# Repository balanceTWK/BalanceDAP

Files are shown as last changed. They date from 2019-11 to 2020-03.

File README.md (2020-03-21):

# BalanceDAP

本项目长期偶尔更新！如有疑问，请[邮箱](mailto:balancetwk@yeah.net)联系我。balanceTWK@yeah.net

代码工程：基于开源免费的 [DAPLink](https://github.com/ARMmbed/DAPLink), [RT-Thread](https://github.com/RT-Thread/rt-thread),

电路板工程：使用开源免费的 [KiCad](http://docs.kicad-pcb.org/) 构建。

本仓库同样开源免费，遵守 [Apache License 2.0 协议](./LICENSE).

## 电路板效果图

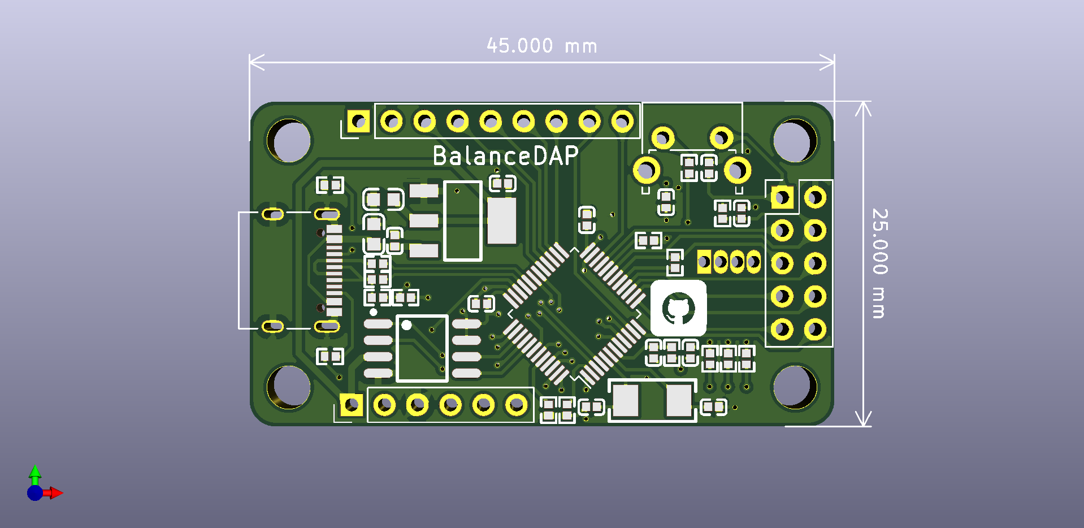
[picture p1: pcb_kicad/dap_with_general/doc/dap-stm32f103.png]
pcb图


## 移植成 rt-thread 后的效果：

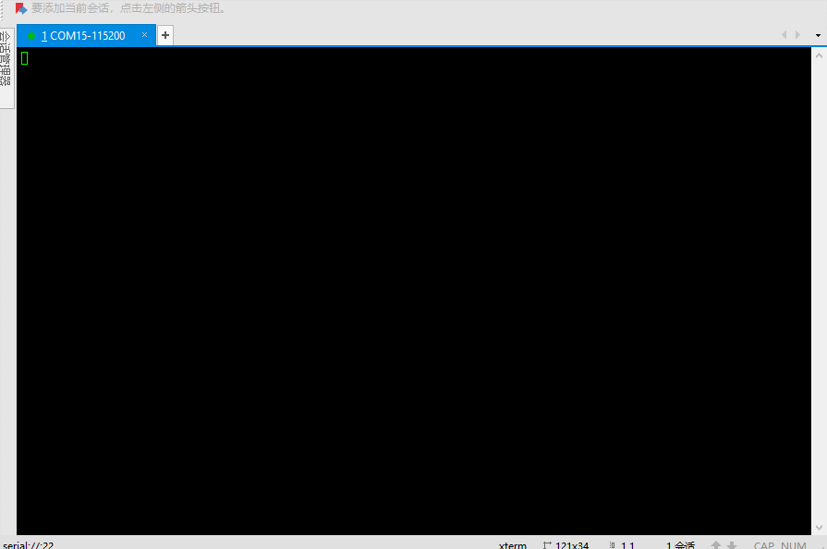
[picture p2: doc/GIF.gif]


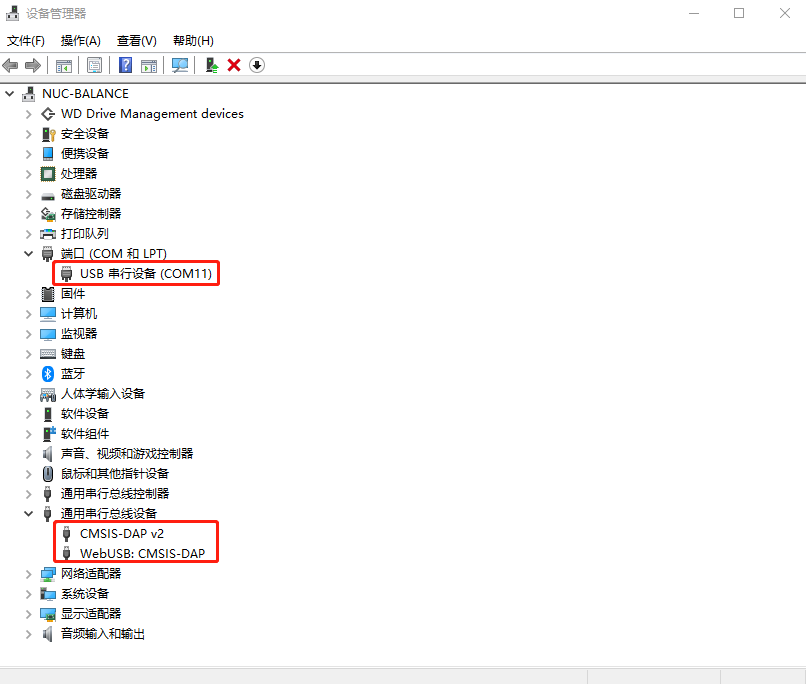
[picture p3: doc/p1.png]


## 问题汇总：

 1. 关于使用 KiCad 打开工程出现原理图缺失元器件的问题：原因是没有安装和作者相同的 KiCad 库，请到此 [链接](https://github.com/balanceTWK/lc_kicad_lib)  处下载。

 2. 关于 MDK 不识别 CMSIS-DAP V2 的问题：参考 /doc 目录下 [Notes.md](doc/Notes.md)。

 ## 感谢：

[@Guozhanxin](https://github.com/Guozhanxin)

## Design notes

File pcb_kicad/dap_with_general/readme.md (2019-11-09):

# DAPLink 全功能版本

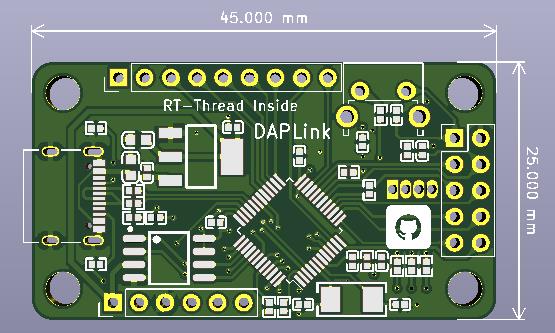
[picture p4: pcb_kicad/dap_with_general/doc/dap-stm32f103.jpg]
pcb图


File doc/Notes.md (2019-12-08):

# µVISION DEBUGGER: µVISION does not detect Mbed DAPLink
Information in this knowledgebase article applies to:

  - MDK version 5.28 and earlier
  - DAPLink versions which are based on CMSIS-DAP V2

## SYMPTOM
µVision version 5.28 or before does not detect an Mbed DAPLink debug adapter which is based on CMSIS-DAP V2.

## CAUSE
An Mbed DAPLink device is a USB composite device which consists of several USB classes (MSC, CDC, HID, WinUSB). Since CMSIS-DAP V2, a WinUSB bulk transfer is used instead of USB-HID. The µVision CMSIS-DAP debug driver always used the first interface (0) of a USB composite device to communicate. However, new DAPLink releases have the MSC on interface 0 and WinUSB on a higher interface number.

## RESOLUTION
Download the attached ZIP file and extract the CMSIS-DAP debug driver file (CMSIS_DAP.dll V0.2.14.1) into the MDK installation folder \ARM\BIN. If the default installation path was used, this is the folder C:\Keil_v5\ARM\BIN

This patch fixes the issues described as 'current limitation #1' for this GitHub commit.

## STATUS
This will be fixed in MDK version 5.29 and later.

## MORE INFORMATION
  - [Mbed DAPLink GitHub repository](https://github.com/ARMmbed/DAPLink)
  - [Arm CMSIS-DAP repository](https://arm-software.github.io/CMSIS_5/DAP/html/index.html)

## ATTACHED FILES
Request the [files attached](./4170.zip) to this knowledgebase article.

Last Reviewed: Wednesday, September 25, 2019

Original [link](http://www.keil.com/support/docs/4170.htm)

---------------------------------------------------------

# µVISION 调试器：µVISION 无法检测到 Mbed DAPLink

本知识库文章中的信息适用于：
  - MDK 版本 5.28 和更早版本
  - 基于 CMSIS-DAP V2 的 DAPLink 版本

## 症状
µVision 版本 5.28 或更低版本无法检测到基于 CMSIS-DAP V2 的 Mbed DAPLink 调试适配器。

## 原因
Mbed DAPLink 设备是一种 USB 复合设备，它由几个 USB 类（MSC，CDC，HID，WinUSB）组成。从 CMSIS-DAP V2 开始，将使用 WinUSB 批量传输代替 USB-HID。µVision CMSIS-DAP 调试驱动程序始终使用 USB 复合设备的第一个接口（0）进行通信。但是，新的 DAPLink 版本在接口 0 上具有 MSC，而在更高接口号上具有 WinUSB。

## 解决方法
下载随附的 ZIP 文件，并将 CMSIS-DAP 调试驱动程序文件（CMSIS_DAP.dll V0.2.14.1）解压缩到 MDK 安装文件夹 \ARM\BIN 中。如果使用默认安装路径，则该文件夹为 C:\Keil_v5\ARM\BIN

该补丁修复了此 GitHub commit 称为'当前限制＃1'的问题。

## 状态
这将在 MDK 5.29 版和更高版本中修复。

## 更多信息
  - [Mbed DAPLink GitHub 存储库](https://github.com/ARMmbed/DAPLink)
  - [Arm CMSIS-DAP 存储库](https://arm-software.github.io/CMSIS_5/DAP/html/index.html)

## 附件
请求附加到此知识库文章的 [文件](./4170.zip)。

上次审查：2019 年 9 月 25 日星期三

原文[链接](http://www.keil.com/support/docs/4170.htm)

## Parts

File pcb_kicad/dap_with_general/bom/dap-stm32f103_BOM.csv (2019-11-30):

Comment | Description | Designator | Footprint | LibRef | Pins | Quantity | PartNumber | url
0402_100nF__104_10%_16V | desc | C11,C4,C12,C13,C3,C14,C15,C5,C8, | 0402_C | libref | 2 | 9
0402_22pF__220_5%_50V | desc | C2,C1, | 0402_C | libref | 2 | 2
0603_10uF__106_10%_10V | desc | C6,C10, | 0603_C | libref | 2 | 2
LOGO | desc | G***, | github | libref | 0 | 1
0402_510Ω__5100_1% | desc | R10,R11,R12,R9, | 0402_R | libref | 2 | 4
0402_1.5KΩ__1501_1% | desc | R13, | 0402_R | libref | 2 | 1
0402_22Ω__22R0_1% | desc | R14,R15, | 0402_R | libref | 2 | 2
0402_0Ω__0R0_1% | desc | R16, | 0402_R | libref | 2 | 1
0402_100KΩ__1003_1% | desc | R3, | 0402_R | libref | 2 | 1
0402_10KΩ__1002_1% | desc | R5,R4,R2,R1, | 0402_R | libref | 2 | 4
0402_100Ω__1000_1% | desc | R6, | 0402_R | libref | 2 | 1
0402_5.1KΩ__5101_1% | desc | R8,R7, | 0402_R | libref | 2 | 2
W25Q128FVSIG_[C35101] | desc | U1, | SOIC-8_208MIL | libref | 8 | 1
STM32F103CBTx | desc | U2, | LQFP-48_7x7mm_P0.5mm | libref | 48 | 1
SOT-223_AMS1117-3.3 | desc | VR1, | SOT-223 | libref | 4 | 1
SMD-5032_2P_8MHz_20ppm_20pF | desc | Y1, | SMD-5032_2P | libref | 2 | 1
Through Hole Items
USB_C_Receptacle_USB2.0 | desc | J1, | USB_C_Receptacle_Palconn_UTC16-G | libref | 22 | 1
Conn_02x05_Top_Bottom | desc | J2, | PinHeader_2x05_P2.54mm_Vertical | libref | 10 | 1
Conn_01x09 | desc | J3, | PinHeader_1x09_P2.54mm_Vertical | libref | 9 | 1
Conn_01x06 | desc | J4, | PinHeader_1x06_P2.54mm_Vertical | libref | 6 | 1
SW_Push | desc | SW1, | SW_Tactile_SPST_Angled_PTS645Vx58-2LFS | libref | 4 | 1
LED_RCBG | desc | D1, | LED_D5.0mm-4_RGB | libref | 4 | 1

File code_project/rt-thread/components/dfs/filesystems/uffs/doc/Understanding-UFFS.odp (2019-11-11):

## Understanding UFFS

Ricky Zheng

< ricky_gz_zheng@yahoo.co.nz >

Created: March 2007

Last modified: Nov 2011

## Content

- Why UFFS ?
- Design goal
- Flash: NOR vs NAND ?
- What's wrong with FAT ?
- UFFS basic idea
  - Serial number
  - Tree in memory
  - Journalizing
- UFFS architecture
  - UFFS device
  - Mount point
  - UFFS nodes tree
  - Mounting UFFS
  - Page spare/UFFS tags
  - Block info cache
  - UFFS page buffer
  - Block recover
  - Bad block management
  - How ECC works ?
  - Flash interface
- What's next ?
  - UFFS2

## Why UFFS ?

- JFFS/JFFS2
  - Can't go out of Linux/MTD
  - Memory monster
- YAFFS/YAFFS2 still consumes too much RAM
  - 64M FLASH, 500 files ==> 410K RAM
- No open source lightweight flash file system exists yet ...

## UFFS design goal

- Ultra low cost
  - Low memory cost
  - Fast booting
- Superb Stability
  - Constant RAM consumption, support static memory allocation
  - Guaranteed integrity across unexpected power losses
  - Bad block tolerant, ECC and ware leveling
- NAND flash friendly
  - Support small (512B) or large page (up to 4KB) size
  - Support SLC and MLC
  - Support software ECC or hardware ECC / RS-ECC
  - Direct flash interface
- Well Emulated on PC platform, easy for debugging

## Flash: NOR vs NAND

- NOR:
  - Random access for read
  - Big block (minimal erase unit)
  - Byte programing
  - Slow erasing/programing
- NAND:
  - Page/spare access for read
  - Small block
  - Page/spare programing (with limited splits/Restricted rewrite)
  - Fast erasing/programing
  - Delivered with bad blocks

## NAND Flash Basic

Page data

Spare

Block

Erase: '0'->'1', Write/Program: '1'->'0'

## What's wrong with FAT

- Need FTL (which may cost many RAM)
- Big FAT table,slow down the whole system
- Vulnerable when unexpectedly interrupted while updating FAT or File info

FAT

File info

Changes

Write File

Changes

File data

Changes

## UFFS basic idea(1)

Parent

Serial

Parent

Serial

Parent

Serial

Parent

Serial

Parent

Serial

Parent

Serial

Parent

Serial

Parent

Serial

Parent

Serial

- Use unique parent/serial number pair to:
  - Identify blocks
  - Build relationships

ROOT

Parent: 16 bit

Serial: 16 bit

## UFFS basic idea(2)

- Build the relationship tree in memory when mounting UFFS:
  - Erased blocks
  - Bad blocks
  - Hash tables (serial number as key)
    - Dir table
    - File table
    - File data table
- Tree node size: 16 bytes
  - Memory cost: 16 * total_blocks

## UFFS basic idea(3)

- Journalizing
  - Write to a new block/page instead of modify the old one.
  - Use circular time stamp: 00->01->11->00>...
  - Check and correct conflicts while mounting UFFS
  - Using “mini-header” eliminates partial page programing requirement

## UFFS Device

- UFFS Device & Mount Point

extern uffs_Device uffs_rootDev;

extern uffs_Device uffs_dataDev;

static struct uffs_mountTableSt femu_MountTbl[] = {

{&uffs_rootDev, 0, 200, "/"},

{&uffs_dataDev, 201, -1, "/data/"},

{NULL, 0, 0, NULL},

};

“/”

“/data/”

UFFS Device ===> Partition
UFFS Device: individual flash ops, cache/buffer, tree nodes ...

## UFFS node tree

- UFFS nodes tree

UFFS device

Bad blocks

Erased blocks

Dir nodes

File nodes

Data nodes

Hash table, serial as the key

block,next

block,next

block,parent,serial,sum,next

block,parent,serial,sum,length(4),next

block,parent,serial,length(2),next

sizeof(TreeNode) = 16B

## UFFS Mounting

- Mounting UFFS

Step 1:

  - Scan page spares*, classify DIR/FILE/DATA nodes
  - Check bad block
  - Check interrupted writing

Step 2:

  - Randomize erased blocks

Step3:

  - Check DATA nodes,take care orphan nodes

Super fast !

* UFFS only read a few spares (normally one or two) from each block rather then all spares !!

UFFS device

Bad blocks

Erased blocks

Dir nodes

File nodes

Data nodes

## UFFS tags

- Page spare/UFFS tags

struct uffs_TagStoreSt {

u32 dirty:1;

u32 valid:1;

u32 type:2;

u32 block_ts:2;

u32 data_len:12;

u32 serial:14;

u32 parent:10;

u32 page_id:6;

u32 reserved:4;

u32 tag_ecc:12;

};

sizeof(struct uffs_TagStoreSt) = 8, small enough to store on spare area

* Note: if using RS-ECC on small page MLC, then tag may store on page data area

## UFFS block info cache

- UFFS block info cache

struct uffs_pageSpareSt {

u8 expired:1;

uffs_Tags tag;

};

struct uffs_blockInfoSt {

struct uffs_blockInfoSt *next;

struct uffs_blockInfoSt *prev;

u16 blockNum;

struct uffs_pageSpareSt *spares;

int expiredCount;

int refCount;

};

uffs_config.h:

MAX_CACHED_BLOCK_INFO(5 ~10)

Memory: 40 bytes for each cached info

## UFFS page buffer

- UFFS page buffer

struct uffs_BufSt{

struct uffs_BufSt *next;

struct uffs_BufSt *prev;

struct uffs_BufSt *nextDirty;

struct uffs_BufSt *prevDirty;

u8 type;

u8 ext_mark;

u16 parent;

u16 serial;

u16 pageID;

u16 mark;

u16 refCount;

u16 dataLen;

u8 * data;

u8 * header;

};

uffs_config.h:

MAX_PAGE_BUFFERS (10 ~ 40)

Memory: (40 + page_size) each buffer

## UFFS page status

Valid page

Discarded page

Free page

- Free page: no page id assigned yet. Free pages are always on the bottom.
- Valid page: the page with a id and have max page offset
- Discarded page: the page with page id, there are one or more pages have the same id and bigger page offset.
- Unknown status: interrupted while writing a page.

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
## UFFS block status

Valid page

Discarded page

Free page

- Bad block
- Free/Erased block
- Non-full loaded block (have one or more free pages)
- Full loaded block (no free page, page id = physical page offset)

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
Bad block

Free block

Non-full loaded block

13

14

15

Full loaded block

## UFFS block recover(1)

- Block recover happens when:
  - No more free pages available inside the block and
  - Data were modified and/or
  - Flush the buffer
- Block recover steps:
  - (1)Get a free/erased block from erased block list
  - (2)Copy pages from old block, write to new block with newer timestamps
  - (3)Erase the old block
  - (4)Put the old block to erased block list
  - Note: (1) and (4) are operating in memory. (2) and (3) identified by timestamps, all steps allow to be interrupted at any time ! (Guaranteed integrity across unexpected power losses)

## UFFS block recover(2)

- No block recover if there are enough free pages

Block 1234

0

Block 1234

0

1

1

Since there are free pages, no block recover happens.

Mark old page as discarded, and generate a new page.

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
Valid page

Discarded page

Free page

## UFFS block recover(3)

- Recover a non-full loaded block

Block 1234

0

Block 5678

0

1

No more free page available in this block, modify any pages from 0-7, or add a new page 8, will cause block recovering.

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
Valid page

Discarded page

Free page

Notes: See uffs_buf.c: static URET _BufFlush_Exist_With_BlockCover ( uffs_Device *dev, TreeNode *node, uffs_blockInfo *bc )

## UFFS block recover(4)

- Recover a full-loaded block

Block 1234

0

Block 5678

0

Modify any page of full-loaded block will cause block recovering.

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
Valid page

Discarded page

Free page

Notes: See uffs_buf.c: static URET _BufFlush_Exist_With_BlockCover ( uffs_Device *dev, TreeNode *node, uffs_blockInfo *bc )

## UFFS Page layout

Status byte

mini-

header

Seal byte

ECC

DATA

Tag

- Mini-header (4B) and DATA on page data area, Tag, ECC and 'seal byte' on spare area
- In some case (for example, when using hardware RS-ECC on small page MLC), you can treat the whole NAND page as one body, blur the page data and spare area boundary.
- The 'status byte': this is the first byte of mini-header. If status byte is not 0xFF – this page is “dirty”, page program already started.
- The 'seal byte': this is the last byte of spare data. If seal byte is not 0xFF – this page is “sealed”, all data and tag/ECC have been programmed successfully.

## UFFS bad block management

- Bad block discover when mounting UFFS
- Bad block discover when read/write/erase
  - Try ECC error correct
  - If ECC fail, there is no way get valid data
  - Do not process bad block immediately, leave it at the end of Read/Write operation.
  - Only handle one bad block during the one read/write operation.
- Check bad block when formating UFFS

## How ECC works ? (1)

- XOR: A ^ B = C
  - 0 ^ 0 = 0
  - 1 ^ 0 = 1
  - 0 ^ 1 = 1
  - 1 ^ 1 = 0
- Knowing any two of A, B and C, will know the rest one.
- UFFS ECC: 3 bytes ECC for 256 bytes data
  - 256 Bytes ==> 2048 Bits ===> 256(row) X 8(col)

## How ECC works ? (2)

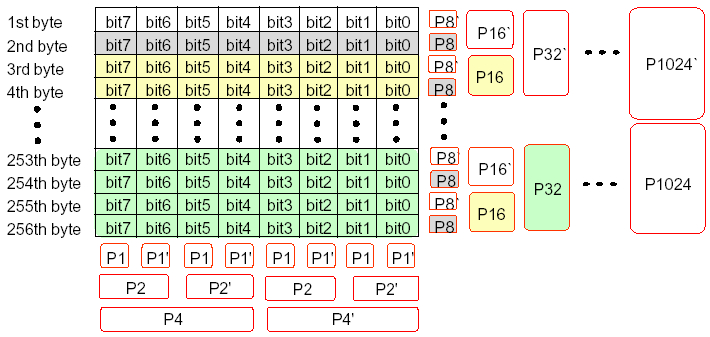
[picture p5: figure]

## UFFS Flash Interface

- struct uffs_FlashOpsSt:
  - Use hardware ECC, or leave it to UFFS
  - Allow driver do the spare layout, or leave it to UFFS
  - Return flash operation status
  - Sequential page programing. No partial page programing.

## UFFS Limitations

- Only one file/dir on one block
- Dynamic wear-leveling, Static wear-leveling is not implemented.

## The next: UFFS2 ?

- Smaller Tree Node (12 bytes), save 25% RAM
- Use NAND block as buffers
- Multiple files/dirs on one block
- Support 8K, 16K page size
- Static wear-leveling
- Symbol link, FIFO file ?
- NOR flash support ? Maybe ...

## The End

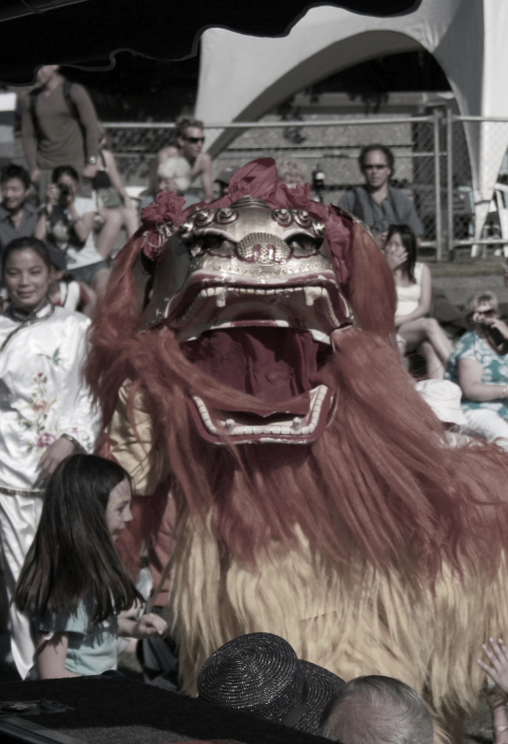
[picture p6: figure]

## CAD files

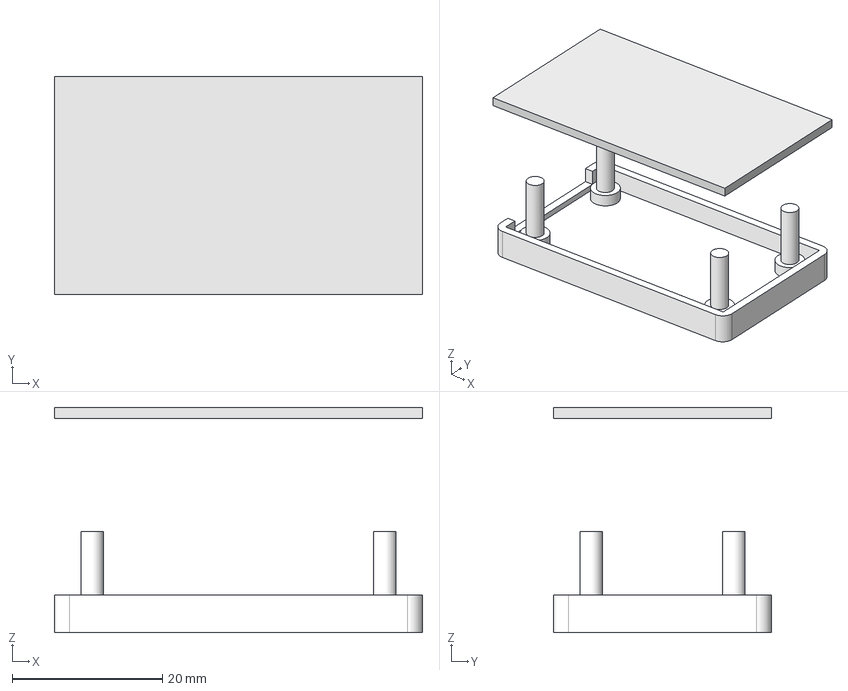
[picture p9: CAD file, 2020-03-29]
FreeCAD/BalanceDAP.FCStd
49.0 x 29.0 x 30.0 mm
盖子

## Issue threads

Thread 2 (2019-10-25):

外部接口情况汇总

balanceTWK, 2019-10-25:
做成邮票孔的形式

| **接口** | **使用引脚** |               **备注**                |
| :------------------------- | :----------: | :-----------------------------------: |
| USB 接口   |    PA11 ；PA12    |  D+使用 PA11 ； D- 使用 PA12   |
| SWD 接口   |    PB0 ；PB13；PB12；PB14    |  NSRSET 使用 PB0；SWCLK 使用 PB13；SWDIO 使用 PB14 PB12   |
| 虚拟串口接口   |    PA2 ；PA3    |  TX 使用 PA2 ； RX 使用 PA3  |
| LED   |    PB6 ；PA9    |  PB6 指示usb连接 ；PA9 指示 USB 的四种状态   |

JTAG 引脚将会预留引出

balanceTWK, 2019-10-25:
目前不打算支持 JTAG 接口，ARM 官方提供的 源码中 JTAG 的 GPIO 翻转函数都只实现了一个空函数。

```c
/** TDI I/O pin: Get Input.
\return Current status of the TDI DAP hardware I/O pin.
*/
static __forceinline uint32_t PIN_TDI_IN(void)
{
    return (0);   // Not available
}

/** TDI I/O pin: Set Output.
\param bit Output value for the TDI DAP hardware I/O pin.
*/
static __forceinline void PIN_TDI_OUT(uint32_t bit)
{
    ;             // Not available
}

// TDO Pin I/O ---------------------------------------------

/** TDO I/O pin: Get Input.
\return Current status of the TDO DAP hardware I/O pin.
*/
static __forceinline uint32_t PIN_TDO_IN(void)
{
    return (0);   // Not available
}

// nTRST Pin I/O -------------------------------------------

/** nTRST I/O pin: Get Input.
\return Current status of the nTRST DAP hardware I/O pin.
*/
static __forceinline uint32_t PIN_nTRST_IN(void)
{
    return (0);   // Not available
}

/** nTRST I/O pin: Set Output.
\param bit JTAG TRST Test Reset pin status:
           - 0: issue a JTAG TRST Test Reset.
           - 1: release JTAG TRST Test Reset.
*/
static __forceinline void PIN_nTRST_OUT(uint32_t bit)
{
    ;             // Not available
}
```

翻了一些 DAPLink 项目的 issue ，感觉 JTAG 可能有坑，所以暂时不实现。

balanceTWK, 2019-10-25:
@lymzzyh @lliu2guang @jiejieTop @Guozhanxin

jiejieTop, 2019-10-25:
OK @balanceTWK

zhdjet, 2019-10-28:
能不能实现串口ISP下载功能啊？另外电路图上有个COM的指示灯，在源码中并没有定义，官方为什么还要画出来呢？

balanceTWK, 2019-10-28:
> 能不能实现串口ISP下载功能啊？另外电路图上有个COM的指示灯，在源码中并没有定义，官方为什么还要画出来呢？

@zhdjet  可以实现ISP功能，但是 daplink 有提供拖拽下载功能，所以ISP功能没有用(等移植成rtt，后期会去实现离线下载功能)。 led灯 不会在邮票孔版本上画出来。多余的引脚会全引出来的。

zhdjet, 2019-11-22:
但是 daplink 有提供拖拽下载功能，
@balanceTWK 虽然官方有这个功能，但是只能一对一的用，不能one to all啊？

zhdjet, 2019-11-27:
@balanceTWK 我已经把全功能版的PCB发出去打板去了，元件也在采购中，决定跟着您玩RT-DAPLINK了！

balanceTWK, 2019-11-27:
> @balanceTWK 我已经把全功能版的PCB发出去打板去了，元件也在采购中，决定跟着您玩RT-DAPLINK了！

别。。。电路有问题，f103 的 USB D+ 需要 1.5k 上拉电阻。

balanceTWK, 2019-11-27:
@zhdjet  给我你的联系方式，到时候免费寄给你一块好了。

zhdjet, 2019-11-28:
好的，谢谢！我把联系方式发您这个邮箱吧。balancetwk@yeah.net，麻烦您注意查收一下。感谢。

zhdjet, 2019-12-04:
@balanceTWK 大师，与之相关的KICAD的库文件能上传一下吗？谢谢！

Closed 2019-10-26.

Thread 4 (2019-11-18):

[已知问题] DAPLink USB 协议栈来自于 MDK 的中间件，无法使用 gcc 编译。只能使用 ARMCC 工具链编译。

balanceTWK, 2019-11-18:
[已知问题] DAPLink USB 协议栈使用了 MDK 的中间件，无法使用 gcc 编译。只能使用 ARMCC5 工具链编译。ARM 官方未来可能会更换支持 gcc 工具链编译的 USB 协议栈。

详情可看以下链接：
[https://github.com/ARMmbed/DAPLink/issues/482#issuecomment-414995922](https://github.com/ARMmbed/DAPLink/issues/482#issuecomment-414995922)

balanceTWK, 2019-11-18:
ARMCC 工具链编译不是免费的。

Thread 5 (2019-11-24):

【记录】 移植到 gcc 的注意事项。

balanceTWK, 2019-11-24:
| 编号 | 原本 | 修改后 | 备注 |
| -------- | ------------|------------| -------- |
| 1 | __weak | __WEAK  |  |
|  |  |  |  |
|  |  |  |  |
|  |  |  |  |
|  |  |  |  |
|  |  |  |  |
|  |  |  |  |

例如：
1. `__weak BOOL USBD_EndPoint0_Setup_CDC_ReqToIF(void)`  -> `__WEAK BOOL USBD_EndPoint0_Setup_CDC_ReqToIF(void)`

balanceTWK, 2019-11-24:
ARM 官方参考：

https://github.com/ARMmbed/DAPLink/pull/678

https://github.com/ARMmbed/DAPLink/issues/197#issuecomment-557828486

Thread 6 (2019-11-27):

【失败记录】这几天有点丧

balanceTWK, 2019-11-27:
1. stm32f103 的 USB D+ 需要外部接上拉 1.5k 电阻，用于设备的枚举。[https://github.com/ARMmbed/mbed-HDK-Eagle-Projects/blob/master/DAPLink/Probes/STM32-DIPDAP/v1.0.0/STM32-DIPDAP-v1.0.0-SCH.pdf](https://github.com/ARMmbed/mbed-HDK-Eagle-Projects/blob/master/DAPLink/Probes/STM32-DIPDAP/v1.0.0/STM32-DIPDAP-v1.0.0-SCH.pdf) 照抄 ARMmbed 官方的原理图，竟然是有问题的。
 2. typec 的电路需要 cc1 cc2 分别用5.1k 电阻接地？存疑。。。
 3. 开源这种东西，在项目前期，就必须抱有不奢求别人帮助，自己孤军奋战的决心。只有项目真的不错后，人们才愿意参与进来。
 4. 以后工作期间不看 USB 相关的资料了。

Closed 2019-11-28.

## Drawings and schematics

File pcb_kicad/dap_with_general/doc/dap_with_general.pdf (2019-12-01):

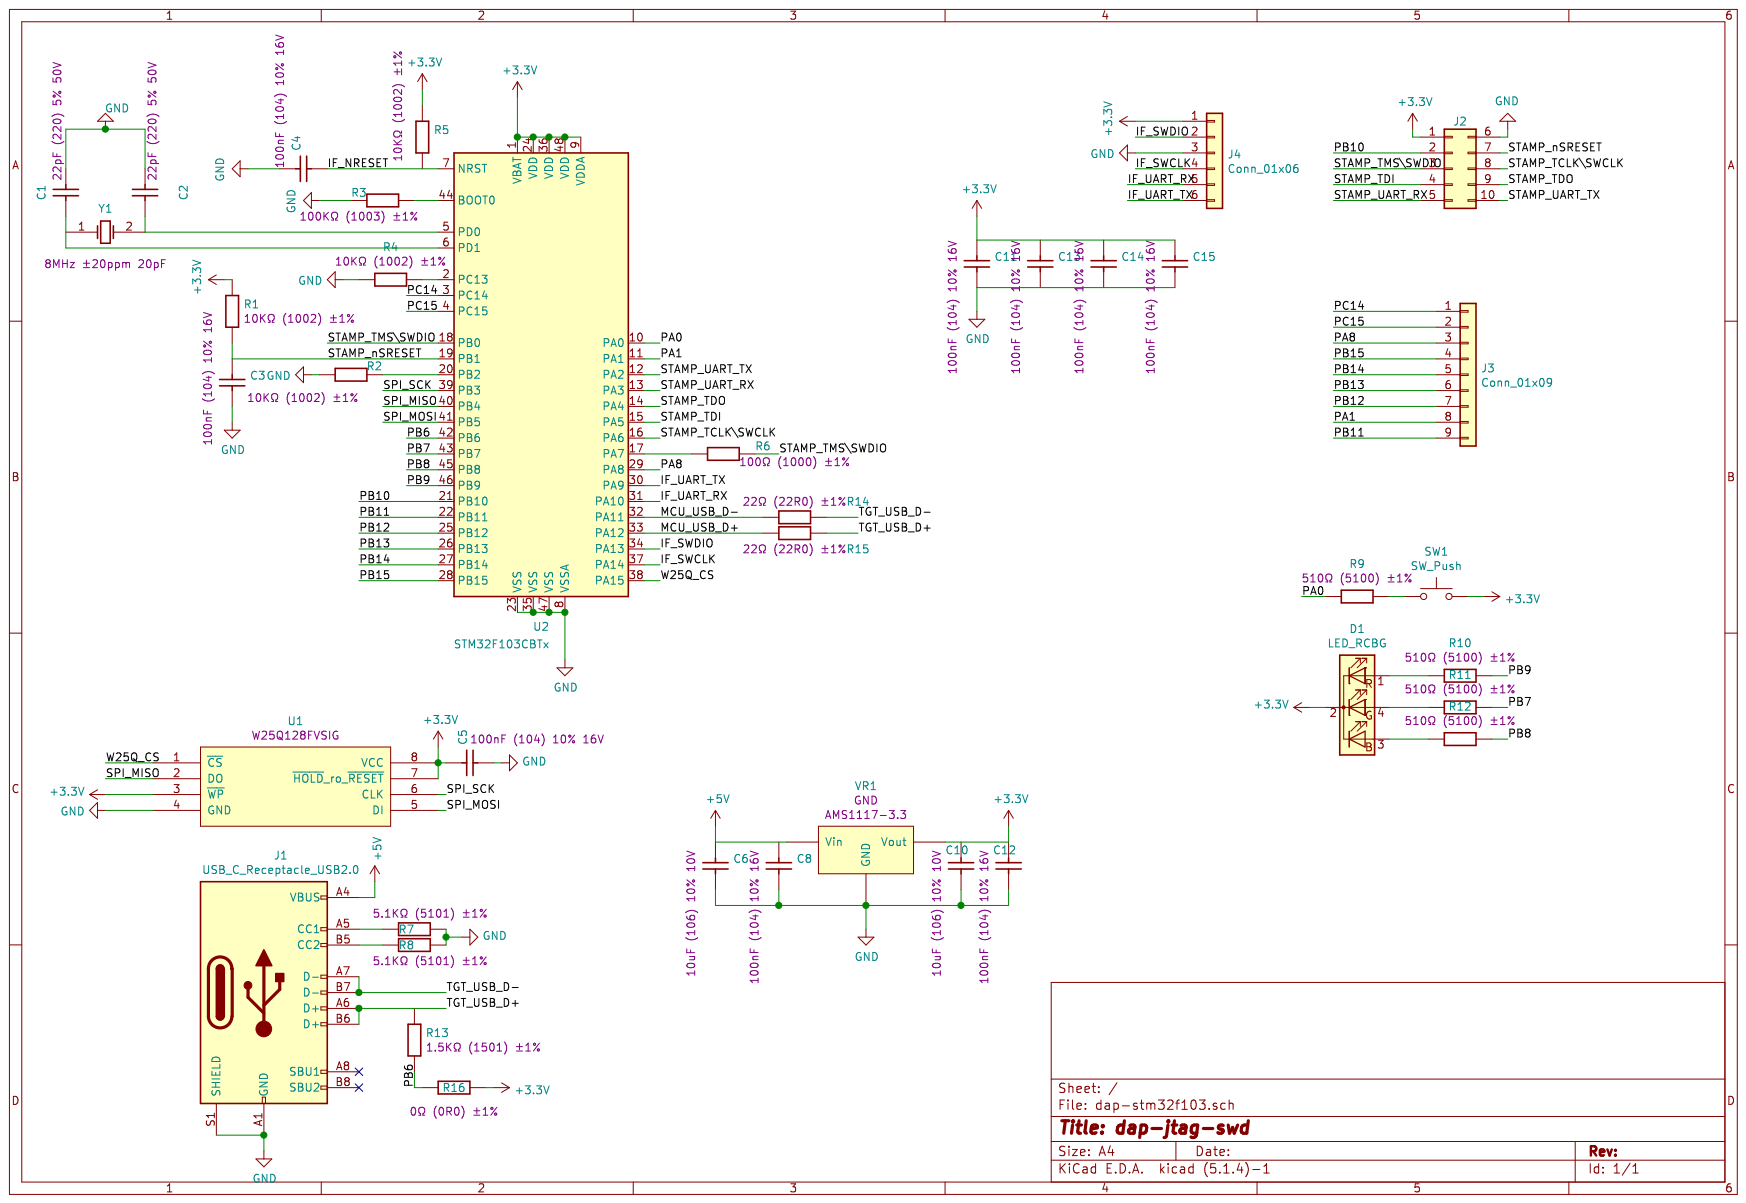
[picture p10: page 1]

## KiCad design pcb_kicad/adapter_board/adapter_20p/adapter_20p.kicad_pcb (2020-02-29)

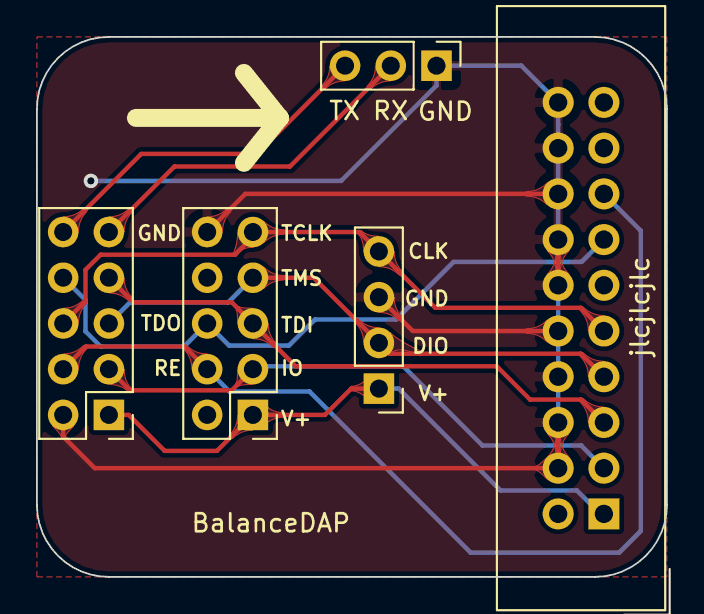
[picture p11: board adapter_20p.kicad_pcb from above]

Board: 2 copper layers, 35.0 x 30.0 mm, 5 parts (0 on the bottom side), 10 nets.

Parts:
J1, J4: Conn_02x05_Top_Bottom; PinHeader_2x05_P2.54mm_Vertical
J2: Conn_02x10_Top_Bottom; IDC-Header_2x10_P2.54mm_Vertical
J3: Conn_01x03; PinHeader_1x03_P2.54mm_Vertical
J5: Conn_01x04; PinHeader_1x04_P2.54mm_Vertical

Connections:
/IO: J1.3, J2.3, J4.3
/RESET: J1.4, J2.15, J4.4
/TCLK\SWCLK: J1.6, J2.9, J4.9, J5.4
/TDI: J1.7, J2.5, J4.5
/TDO: J1.8, J2.13, J4.6
/TMS\SWDIO: J1.5, J2.7, J4.7, J5.2
/UART_RX: J1.9, J3.2
/UART_TX: J1.10, J3.3
/VREF+: J1.1, J2.1, J4.1, J5.1
GND: J1.2, J2.4, J2.6, J2.8, J2.10, J2.12, J2.14, J2.16, J2.18, J2.20, J3.1, J4.10, J5.3

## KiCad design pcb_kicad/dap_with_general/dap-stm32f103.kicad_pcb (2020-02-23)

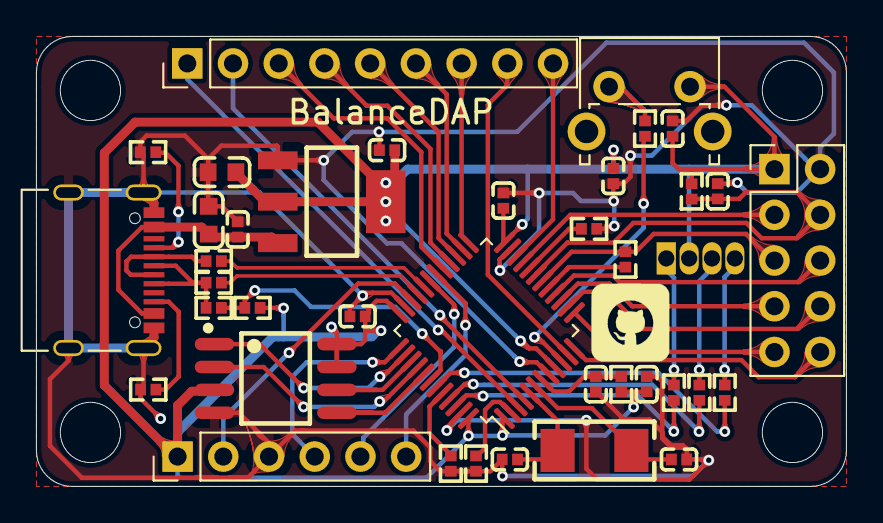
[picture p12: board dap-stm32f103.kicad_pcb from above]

Board: 2 copper layers, 45.0 x 25.0 mm, 39 parts (1 on the bottom side), 50 nets.

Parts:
C1, C2: 0402_22pF__220_5%_50V; 0402_C
C3, C4, C5, C8, C11, C12, C13, C14, C15: 0402_100nF__104_10%_16V; 0402_C
C6, C10: 0603_10uF__106_10%_10V; 0603_C
D1: LED_RCBG; LED_D5.0mm-4_RGB
J1: USB_C_Receptacle_USB2.0; USB_C_Receptacle_Palconn_UTC16-G
J2: Conn_02x05_Top_Bottom; PinHeader_2x05_P2.54mm_Vertical
J3: Conn_01x09; PinHeader_1x09_P2.54mm_Vertical
J4: Conn_01x06; PinHeader_1x06_P2.54mm_Vertical
R1, R2, R4, R5: 0402_10KΩ__1002_1%; 0402_R
R3: 0402_100KΩ__1003_1%; 0402_R
R6: 0402_100Ω__1000_1%; 0402_R
R7, R8: 0402_5.1KΩ__5101_1%; 0402_R
R9, R10, R11, R12: 0402_510Ω__5100_1%; 0402_R
R13: 0402_1.5KΩ__1501_1%; 0402_R
R14, R15: 0402_22Ω__22R0_1%; 0402_R
R16: 0402_0Ω__0R0_1%; 0402_R
SW1: SW_Push; SW_Tactile_SPST_Angled_PTS645Vx58-2LFS
U1: W25Q128FVSIG_[C35101]; SOIC-8_208MIL
U2: STM32F103CBTx; LQFP-48_7x7mm_P0.5mm
VR1: SOT-223_AMS1117-3.3; SOT-223
Y1: SMD-5032_2P_8MHz_20ppm_20pF; SMD-5032_2P

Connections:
+3V3: C5.1, C10.1, C11.1, C12.1, C13.1, C14.1, C15.1, D1.2, J2.1, J4.1, R1.1, R5.1, R16.2, SW1.2, U1.3, U1.7, U1.8, U2.1, U2.9, U2.24, U2.36, U2.48, VR1.2
+5V: C6.1, C8.1, J1.A4, J1.A9, J1.B4, J1.B9, VR1.3
/IF_NRESET: C4.2, R5.2, U2.7
/IF_SWCLK: J4.4, U2.37
/IF_SWDIO: J4.2, U2.34
/IF_UART_RX: J4.5, U2.31
/IF_UART_TX: J4.6, U2.30
/MCU_USB_D+: R15.1, U2.33
/MCU_USB_D-: R14.1, U2.32
/PA0: R9.1, U2.10
/PA1: J3.8, U2.11
/PA8: J3.3, U2.29
/PB6: R13.2, R16.1, U2.42
/PB7: R11.2, U2.43
/PB8: R12.2, U2.45
/PB9: R10.2, U2.46
/PB10: J2.2, U2.21
/PB11: J3.9, U2.22
/PB12: J3.7, U2.25
/PB13: J3.6, U2.26
/PB14: J3.5, U2.27
/PB15: J3.4, U2.28
/PC14: J3.1, U2.3
/PC15: J3.2, U2.4
/SPI_MISO: U1.2, U2.40
/SPI_MOSI: U1.5, U2.41
/SPI_SCK: U1.6, U2.39
/STAMP_TCLK\SWCLK: J2.8, U2.16
/STAMP_TDI: J2.4, U2.15
/STAMP_TDO: J2.9, U2.14
/STAMP_TMS\SWDIO: J2.3, R6.2, U2.18
/STAMP_UART_RX: J2.5, U2.13
/STAMP_UART_TX: J2.10, U2.12
/STAMP_nSRESET: C3.1, J2.7, R1.2, U2.19
/TGT_USB_D+: J1.A6, J1.B6, R13.1, R15.2
/TGT_USB_D-: J1.A7, J1.B7, R14.2
/W25Q_CS: U1.1, U2.38
GND: C1.1, C2.1, C3.2, C4.1, C5.2, C6.2, C8.2, C10.2, C11.2, C12.2, C13.2, C14.2, C15.2, J1.A1, J1.A12, J1.B1, J1.B12, J1.S1, J2.6, J4.3, R2.2, R3.1, R4.1, R7.2, R8.2, U1.4, U2.8, U2.23, U2.35, U2.47, VR1.1
unnamed: C1.2, U2.6, Y1.1
unnamed: C2.2, U2.5, Y1.2
unnamed: D1.1, R10.1
unnamed: D1.3, R12.1
unnamed: D1.4, R11.1
unnamed: J1.A5, R7.1
unnamed: J1.B5, R8.1
unnamed: R2.1, U2.20
unnamed: R3.2, U2.44
unnamed: R4.2, U2.2
unnamed: R6.1, U2.17
unnamed: R9.2, SW1.1

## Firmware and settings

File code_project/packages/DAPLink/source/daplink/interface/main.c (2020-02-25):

/**
 * @file    main.c
 * @brief   Entry point for interface program logic
 *
 * DAPLink Interface Firmware
 * Copyright (c) 2009-2019, ARM Limited, All Rights Reserved
 * SPDX-License-Identifier: Apache-2.0
 *
 * Licensed under the Apache License, Version 2.0 (the "License"); you may
 * not use this file except in compliance with the License.
 * You may obtain a copy of the License at
 *
 * http://www.apache.org/licenses/LICENSE-2.0
 *
 * Unless required by applicable law or agreed to in writing, software
 * distributed under the License is distributed on an "AS IS" BASIS, WITHOUT
 * WARRANTIES OR CONDITIONS OF ANY KIND, either express or implied.
 * See the License for the specific language governing permissions and
 * limitations under the License.
 */

#include "string.h"
#include "stdio.h"
#include "stdint.h"

#include "cmsis_os2.h"
#include "rtx_os.h"
#include "rl_usb.h"
#include "main.h"
#include "gpio.h"
#include "uart.h"
#include "tasks.h"
#include "target_reset.h"
#include "swd_host.h"
#include "info.h"
#include "settings.h"
#include "daplink.h"
#include "util.h"
#include "DAP.h"
#include "bootloader.h"
#include "cortex_m.h"
#include "sdk.h"
#include "target_family.h"
#include "target_board.h"

#ifdef DRAG_N_DROP_SUPPORT
#include "vfs_manager.h"
#include "flash_intf.h"
#include "flash_manager.h"
#endif

// Event flags for main task
// Timers events
#define FLAGS_MAIN_90MS         (1 << 0)
#define FLAGS_MAIN_30MS         (1 << 1)
// Reset events
#define FLAGS_MAIN_RESET        (1 << 2)
// Other Events
#define FLAGS_MAIN_POWERDOWN    (1 << 4)
#define FLAGS_MAIN_DISABLEDEBUG (1 << 5)
#define FLAGS_MAIN_PROC_USB     (1 << 9)
// Used by cdc when an event occurs
#define FLAGS_MAIN_CDC_EVENT    (1 << 11)
// Used by msd when flashing a new binary
#define FLAGS_LED_BLINK_30MS    (1 << 6)

// Timing constants (in 90mS ticks)
// USB busy time (~3 sec)
#define USB_BUSY_TIME           (33)
// Delay before a USB device connect may occur (~1 sec)
#define USB_CONNECT_DELAY       (11)
// Timeout for USB being configured (~2 sec)
#define USB_CONFIGURE_TIMEOUT   (22)
// Delay before target may be taken out of reset or reprogrammed after startup
#define STARTUP_DELAY           (1)

// Decrement to zero
#define DECZERO(x)              (x ? --x : 0)

//default hid led settings
#ifndef HID_LED_DEF
#define HID_LED_DEF GPIO_LED_OFF
#endif

//default cdc led settings
#ifndef CDC_LED_DEF
#define CDC_LED_DEF GPIO_LED_OFF
#endif

//default msc led settings
#ifndef MSC_LED_DEF
#define MSC_LED_DEF GPIO_LED_OFF
#endif

// Reference to our main task
osThreadId_t main_task_id;
static uint32_t s_main_thread_cb[WORDS(sizeof(osRtxThread_t))];
static uint64_t s_main_task_stack[MAIN_TASK_STACK / sizeof(uint64_t)];
static const osThreadAttr_t k_main_thread_attr = {
        .name = "main",
        .cb_mem = s_main_thread_cb,
        .cb_size = sizeof(s_main_thread_cb),
        .stack_mem = s_main_task_stack,
        .stack_size = sizeof(s_main_task_stack),
        .priority = MAIN_TASK_PRIORITY,
    };

static uint32_t s_timer_30ms_cb[WORDS(sizeof(osRtxTimer_t))];
static const osTimerAttr_t k_timer_30ms_attr = {
        .name = "30ms",
        .cb_mem = s_timer_30ms_cb,
        .cb_size = sizeof(s_timer_30ms_cb),
    };

// USB busy LED state; when TRUE the LED will flash once using 30mS clock tick
static uint8_t hid_led_usb_activity = 0;
static uint8_t cdc_led_usb_activity = 0;
static uint8_t msc_led_usb_activity = 0;
static main_led_state_t hid_led_state = MAIN_LED_FLASH;
static main_led_state_t cdc_led_state = MAIN_LED_FLASH;
static main_led_state_t msc_led_state = MAIN_LED_FLASH;

// Global state of usb
main_usb_connect_t usb_state;
static bool usb_test_mode = false;

// Timer task, set flags every 30mS and 90mS
void timer_task_30mS(void * arg)
{
    static uint32_t i = 0;
    osThreadFlagsSet(main_task_id, FLAGS_MAIN_30MS);
    if (!(i++ % 3)) {
        osThreadFlagsSet(main_task_id, FLAGS_MAIN_90MS);
    }
}

// Functions called from other tasks to trigger events in the main task
// parameter should be reset type??
void main_reset_target(uint8_t send_unique_id)
{
    osThreadFlagsSet(main_task_id, FLAGS_MAIN_RESET);
    return;
}

// Flash HID LED using 30mS tick
void main_blink_hid_led(main_led_state_t state)
{
    hid_led_usb_activity = 1;
    hid_led_state = state;
    return;
}

// Flash CDC LED using 30mS tick
void main_blink_cdc_led(main_led_state_t state)
{
    cdc_led_usb_activity = 1;
    cdc_led_state = state;
    return;
}

// Flash MSC LED using 30mS tick
void main_blink_msc_led(main_led_state_t state)
{
    msc_led_usb_activity = 1;
    msc_led_state = state;
    return;
}

// Power down the interface
void main_powerdown_event(void)
{
    osThreadFlagsSet(main_task_id, FLAGS_MAIN_POWERDOWN);
    return;
}

// Disable debug on target
void main_disable_debug_event(void)
{
    osThreadFlagsSet(main_task_id, FLAGS_MAIN_DISABLEDEBUG);
    return;
}

// Start CDC processing
void main_cdc_send_event(void)
{
    osThreadFlagsSet(main_task_id, FLAGS_MAIN_CDC_EVENT);
    return;
}

void main_usb_set_test_mode(bool enabled)
{
    usb_test_mode = enabled;
}

void USBD_SignalHandler()
{
    osThreadFlagsSet(main_task_id, FLAGS_MAIN_PROC_USB);
}

extern void cdc_process_event(void);

void main_task(void * arg)
{
    // State processing
    uint16_t flags = 0;
    // LED
    gpio_led_state_t hid_led_value = HID_LED_DEF;
    gpio_led_state_t cdc_led_value = CDC_LED_DEF;
    gpio_led_state_t msc_led_value = MSC_LED_DEF;
    // USB
    uint32_t usb_state_count = USB_BUSY_TIME;
    uint32_t usb_no_config_count = USB_CONFIGURE_TIMEOUT;
    // button state
    uint8_t reset_pressed = 0;
#ifdef PBON_BUTTON
    uint8_t power_on = 1;
#endif

    // Initialize settings - required for asserts to work
    config_init();
    // Update bootloader if it is out of date
    bootloader_check_and_update();
    // leds
    gpio_init();
    // Turn to LED default settings
    gpio_set_hid_led(hid_led_value);
    gpio_set_cdc_led(cdc_led_value);
    gpio_set_msc_led(msc_led_value);
    // Initialize the DAP
    DAP_Setup();

    // do some init with the target before USB and files are configured
    if (g_board_info.prerun_board_config) {
        g_board_info.prerun_board_config();
    }

    //initialize the family
    init_family();

    if (g_target_family && g_target_family->prerun_target_config) {
        g_target_family->prerun_target_config();
    }

    //setup some flags
    if (g_board_info.flags & kEnableUnderResetConnect) {
        swd_set_reset_connect(CONNECT_UNDER_RESET);
    }
    if (g_board_info.flags & kEnablePageErase) {
#ifdef DRAG_N_DROP_SUPPORT
        flash_manager_set_page_erase(true);
#endif
    }

    // Update versions and IDs
    info_init();
    // USB
    usbd_init();
#ifdef DRAG_N_DROP_SUPPORT
    vfs_mngr_fs_enable((config_ram_get_disable_msd()==0));
#endif
    usbd_connect(0);
    usb_state = USB_CONNECTING;
    usb_state_count = USB_CONNECT_DELAY;

    // Start timer tasks
    osTimerId_t tmr_id = osTimerNew(timer_task_30mS, osTimerPeriodic, NULL, &k_timer_30ms_attr);
    osTimerStart(tmr_id, 3);
    while (1) {
        flags = osThreadFlagsWait(FLAGS_MAIN_RESET             // Put target in reset state
                       | FLAGS_MAIN_90MS            // 90mS tick
                       | FLAGS_MAIN_30MS            // 30mS tick
                       | FLAGS_MAIN_POWERDOWN       // Power down interface
                       | FLAGS_MAIN_DISABLEDEBUG    // Disable target debug
                       | FLAGS_MAIN_PROC_USB        // process usb events
                       | FLAGS_MAIN_CDC_EVENT       // cdc event
                       , osFlagsWaitAny
                       , osWaitForever);

        if (flags & FLAGS_MAIN_PROC_USB) {
            if (usb_test_mode) {
                // When in USB test mode Insert a delay to
                // simulate worst-case behavior.
                osDelay(1);
            }
            USBD_Handler();
        }

        if (flags & FLAGS_MAIN_RESET) {
            target_set_state(RESET_RUN);
        }

        if (flags & FLAGS_MAIN_POWERDOWN) {
            // Disable debug
            target_set_state(NO_DEBUG);
            // Disable board power before USB is disconnected.
            gpio_set_board_power(false);
            // Disconnect USB
            usbd_connect(0);
            // Turn off LED
            gpio_set_hid_led(GPIO_LED_OFF);
            gpio_set_cdc_led(GPIO_LED_OFF);
            gpio_set_msc_led(GPIO_LED_OFF);

            // TODO: put the interface chip in sleep mode
            while (1);
        }

        if (flags & FLAGS_MAIN_DISABLEDEBUG) {
            // Disable debug
            target_set_state(NO_DEBUG);
        }

        if (flags & FLAGS_MAIN_CDC_EVENT) {
            cdc_process_event();
        }

        if (flags & FLAGS_MAIN_90MS) {
            // Update USB busy status
#ifdef DRAG_N_DROP_SUPPORT
            vfs_mngr_periodic(90); // FLAGS_MAIN_90MS
#endif
            // Update USB connect status
            switch (usb_state) {
                case USB_DISCONNECTING:
                    usb_state = USB_DISCONNECTED;
                    // Disable board power before USB is disconnected.
                    gpio_set_board_power(false);
                    usbd_connect(0);
                    break;

                case USB_CONNECTING:
                    // Wait before connecting
                    if (DECZERO(usb_state_count) == 0) {
                        usbd_connect(1);
                        usb_state = USB_CHECK_CONNECTED;
                        // Reset connect timeout
                        usb_no_config_count = USB_CONFIGURE_TIMEOUT;
                    }

                    break;

                case USB_CHECK_CONNECTED:
                    if (usbd_configured()) {
                        // Let the HIC enable power to the target now that high power has been negotiated.
                        gpio_set_board_power(true);

                        usb_state = USB_CONNECTED;
                    }
                    else if (DECZERO(usb_no_config_count) == 0) {
                        // USB configuration timed out, which most likely indicates that the HIC is
                        // powered by a USB wall wart or similar power source. Go ahead and enable
                        // board power.
                        gpio_set_board_power(true);
                    }

                    break;

                case USB_CONNECTED:
                case USB_DISCONNECTED:
                default:
                    break;
            }
        }

        // 30mS tick used for flashing LED when USB is busy
        if (flags & FLAGS_MAIN_30MS) {

            // handle reset button without eventing
            if (!reset_pressed && gpio_get_reset_btn_fwrd()) {
#ifdef DRAG_N_DROP_SUPPORT
               if (!flash_intf_target->flash_busy()) //added checking if flashing on target is in progress
#endif
                {
                    // Reset button pressed
                    target_set_state(RESET_HOLD);
                    reset_pressed = 1;
                }
            } else if (reset_pressed && !gpio_get_reset_btn_fwrd()) {
                // Reset button released
                target_set_state(RESET_RUN);
                reset_pressed = 0;
            }

#ifdef PBON_BUTTON
            // handle PBON pressed
            if(gpio_get_pbon_btn())
            {
                if(power_on)
                {
                    // Loop till PBON is pressed
                    while (gpio_get_pbon_btn()) {;}
                    // Power button released when target was running
                    target_set_state(SHUTDOWN);
                    power_on = 0;
                }
                else
                {
                    // Loop till PBON is pressed
                    while (gpio_get_pbon_btn()) {;}
                    // Power button released when target was already powered off
                    target_set_state(POWER_ON);
                    power_on = 1;
                }
            }
#endif

            // DAP LED
            if (hid_led_usb_activity) {

                if ((hid_led_state == MAIN_LED_FLASH) || (hid_led_state == MAIN_LED_FLASH_PERMANENT)) {
                    // Toggle LED value
                    hid_led_value = GPIO_LED_ON == hid_led_value ? GPIO_LED_OFF : GPIO_LED_ON;

                    // If in flash mode stop after one cycle
                    if ((HID_LED_DEF == hid_led_value) && (MAIN_LED_FLASH == hid_led_state)) {
                        hid_led_usb_activity = 0;
                        hid_led_state = MAIN_LED_DEF;
                    }
                } else {
                    //LED next state is MAIN_LED_DEF
                    hid_led_value = HID_LED_DEF;
                    hid_led_usb_activity = 0;
                }

                // Update hardware
                gpio_set_hid_led(hid_led_value);
            }

            // MSD LED
            if (msc_led_usb_activity) {

                if ((msc_led_state == MAIN_LED_FLASH) || (msc_led_state == MAIN_LED_FLASH_PERMANENT)) {
                    // Toggle LED value
                    msc_led_value = GPIO_LED_ON == msc_led_value ? GPIO_LED_OFF : GPIO_LED_ON;

                    // If in flash mode stop after one cycle
                    if ((MSC_LED_DEF == msc_led_value) && (MAIN_LED_FLASH == msc_led_state)) {
                        msc_led_usb_activity = 0;
                        msc_led_state = MAIN_LED_DEF;
                    }
                } else {
                    //LED next state is MAIN_LED_DEF
                    msc_led_value = MSC_LED_DEF;
                    msc_led_usb_activity = 0;
                }

                // Update hardware
                gpio_set_msc_led(msc_led_value);
            }

            // CDC LED
            if (cdc_led_usb_activity) {

                if ((cdc_led_state == MAIN_LED_FLASH) || (cdc_led_state == MAIN_LED_FLASH_PERMANENT)){
                    // Toggle LED value
                    cdc_led_value = GPIO_LED_ON == cdc_led_value ? GPIO_LED_OFF : GPIO_LED_ON;

                    // If in flash mode stop after one cycle
                    if ((CDC_LED_DEF == cdc_led_value) && (MAIN_LED_FLASH == cdc_led_state)) {
                        cdc_led_usb_activity = 0;
                        cdc_led_state = MAIN_LED_DEF;
                    }
                }else{
                    //LED next state is MAIN_LED_DEF
                    cdc_led_value = CDC_LED_DEF;
                    cdc_led_usb_activity = 0;
                }

                // Update hardware
                gpio_set_cdc_led(cdc_led_value);
            }
        }
    }
}

int main(void)
{
    // Explicitly set the vector table since the bootloader might not set
    // it to what we expect.
#if DAPLINK_ROM_BL_SIZE > 0
    SCB->VTOR = SCB_VTOR_TBLOFF_Msk & DAPLINK_ROM_IF_START;
#endif
    // initialize vendor sdk
    sdk_init();

    // Initialize CMSIS-RTOS
    osKernelInitialize();

    // Create application main thread
    main_task_id = osThreadNew(main_task, NULL, &k_main_thread_attr);

    // Start thread execution
    osKernelStart();

    // Should never reach here!
    for (;;) {}
}

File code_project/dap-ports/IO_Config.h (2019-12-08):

/**
 * @file    IO_Config.h
 * @brief
 *
 * DAPLink Interface Firmware
 * Copyright (c) 2009-2016, ARM Limited, All Rights Reserved
 * SPDX-License-Identifier: Apache-2.0
 *
 * Licensed under the Apache License, Version 2.0 (the "License"); you may
 * not use this file except in compliance with the License.
 * You may obtain a copy of the License at
 *
 * http://www.apache.org/licenses/LICENSE-2.0
 *
 * Unless required by applicable law or agreed to in writing, software
 * distributed under the License is distributed on an "AS IS" BASIS, WITHOUT
 * WARRANTIES OR CONDITIONS OF ANY KIND, either express or implied.
 * See the License for the specific language governing permissions and
 * limitations under the License.
 */

#ifndef __IO_CONFIG_H__
#define __IO_CONFIG_H__

#include "stm32f1xx.h"
#include "compiler.h"
#include "daplink.h"

COMPILER_ASSERT(DAPLINK_HIC_ID == DAPLINK_HIC_ID_STM32F103XB);

//USB control pin
#define USB_CONNECT_PORT_ENABLE()    __HAL_RCC_GPIOB_CLK_ENABLE()
#define USB_CONNECT_PORT_DISABLE()   __HAL_RCC_GPIOB_CLK_DISABLE()
#define USB_CONNECT_PORT             GPIOB
#define USB_CONNECT_PIN              GPIO_PIN_6
#define USB_CONNECT_ON()             (USB_CONNECT_PORT->BSRR = USB_CONNECT_PIN)
#define USB_CONNECT_OFF()            (USB_CONNECT_PORT->BRR  = USB_CONNECT_PIN)

//Connected LED
#define CONNECTED_LED_PORT           GPIOB
#define CONNECTED_LED_PIN            GPIO_PIN_7
#define CONNECTED_LED_PIN_Bit        7

//When bootloader, disable the target port(not used)
#define POWER_EN_PIN_PORT            GPIOB
#define POWER_EN_PIN                 GPIO_PIN_15
#define POWER_EN_Bit                 15

// nRESET OUT Pin
#define nRESET_PIN_PORT              GPIOB
#define nRESET_PIN                   GPIO_PIN_1
#define nRESET_PIN_Bit               1

//SWD
#define SWCLK_TCK_PIN_PORT           GPIOA
#define SWCLK_TCK_PIN                GPIO_PIN_6
#define SWCLK_TCK_PIN_Bit            6

#define SWDIO_OUT_PIN_PORT           GPIOB
#define SWDIO_OUT_PIN                GPIO_PIN_0
#define SWDIO_OUT_PIN_Bit            0

#define SWDIO_IN_PIN_PORT            GPIOA
#define SWDIO_IN_PIN                 GPIO_PIN_7
#define SWDIO_IN_PIN_Bit             7

//LEDs
//USB status LED
#define RUNNING_LED_PORT             GPIOB
#define RUNNING_LED_PIN              GPIO_PIN_7
#define RUNNING_LED_Bit              7

#define PIN_HID_LED_PORT             GPIOB
#define PIN_HID_LED                  GPIO_PIN_8
#define PIN_HID_LED_Bit              8

#define PIN_CDC_LED_PORT             GPIOB
#define PIN_CDC_LED                  GPIO_PIN_9
#define PIN_CDC_LED_Bit              9

#define PIN_MSC_LED_PORT             GPIOB
#define PIN_MSC_LED                  GPIO_PIN_9
#define PIN_MSC_LED_Bit              9


#endif

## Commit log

2019-10-05 [first] pcb project
    [dap-stm32f103.kicad_pcb, dap-stm32f103.sch]
2019-10-09 [update] pcb
    [dap-stm32f103.sch]
2019-10-10 [update] pcb sch
    [dap-stm32f103.sch]
2019-10-13 [update] SCH
    [dap-stm32f103.sch]
2019-10-15 [update] SCH done
    [dap-stm32f103.sch]
2019-10-19 [pcb] 20%
    [dap-stm32f103.kicad_pcb]
2019-10-20 [update] pcb 25%
    [dap-stm32f103.kicad_pcb]
2019-10-21 [update] pcb 连线完成
    [dap-stm32f103.kicad_pcb, dap-stm32f103.sch]
2019-10-21 [pcb] done
    [dap-stm32f103.kicad_pcb]
2019-10-27 [update] stamp footprint
    [dap-stm32f103.kicad_pcb, dap-stm32f103.sch]
2019-10-29 [done] stamp pcb
    [dap-stm32f103.kicad_pcb, dap-stm32f103.sch]
2019-10-31 [delete] Useless files
    [dap-stm32f103-B_Cu.gbr, dap-stm32f103-B_Mask.gbr, dap-stm32f103-B_Paste.gbr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]
2019-11-01 [update] Gerber files
    [dap-stm32f103.kicad_pcb]
2019-11-02 [update] directory
    [dap-stm32f103-B_Cu.gbr, dap-stm32f103-B_Mask.gbr, dap-stm32f103-B_Paste.gbr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]
2019-11-02 [init] pcb general
    [dap-stm32f103.kicad_pcb, dap-stm32f103.sch]
2019-11-08 [update] pcb general
    [dap-stm32f103-B_Cu.gbr, dap-stm32f103-B_Mask.gbr, dap-stm32f103-B_Paste.gbr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]
2019-11-09 [update] pcb general gerber
    [dap-stm32f103-B_Cu.gbr, dap-stm32f103-B_Mask.gbr, dap-stm32f103-B_Paste.gbr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]
2019-11-09 [update] pcb general readme.md
2019-11-11 [first] add code_project
    [kconfig-language.txt, kconfig.txt]
2019-11-15 [add] dap_with_general/bom/*.csv
    [dap-stm32f103_BOM.csv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]
2019-11-19 [update] pcb_kicad/dap_with_general
    [dap-stm32f103-B_Cu.gbr, dap-stm32f103-B_Mask.gbr, dap-stm32f103-B_Paste.gbr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]
2019-11-19 [update] bom/dap-stm32f103_POS.csv
    [dap-stm32f103_POS.csv]
2019-11-21 [update] SWD pin number
2019-11-30 [delete] stamp pcb
    [dap-stm32f103-B_Cu.gbr, dap-stm32f103-B_Mask.gbr, dap-stm32f103-B_Paste.gbr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]
2019-11-30 [update] BOM and POS
    [dap-stm32f103_BOM.csv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]
2019-12-05 [update] usb connect pin
2019-12-08 添加注意事项文档。
2020-02-01 [update] CubeMX_Config : spi and rtc
2020-02-01 [add] spi flash
2020-02-02 [add] rtos/rt-thread-3.1.3/
2020-02-02 [change] RTX --> rt-thread,!!!but only led runing.
2020-02-03 [update] rt-thread os is ok,but daplink not adaptive!
2020-02-03 [BUG] osThreadFlagsSet:rt_thread_resume(rt_thread_self()); -> rt_thread_resume(&thread_cb->thread);
    [main.c]
2020-02-04 [tag] update osThreadFlagsxxx; TEST OK！
2020-02-19 [code_project] Add rt-thread device framework support.1. Add uart drivers.2. Add spi flash driver and components.3. Add the finsh component.
2020-02-29 [add] pcb adapter
    [adapter_20p-B_Cu.gbr, adapter_20p-B_Mask.gbr, adapter_20p-B_Paste.gbr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]
2020-03-04 添加 littlefs 支持
2020-03-15 [first add] FreeCAD
    [BalanceDAP.FCStd]
2020-03-21 将 hal 库移到外部
2020-03-21 将port部分抽离出来
2020-03-21 使用官方 stm32 hal 库
2020-03-21 还原启动文件修改
2020-03-29 [FreeCAD] BalanceDAP.FCStd
    [BalanceDAP.FCStd]
